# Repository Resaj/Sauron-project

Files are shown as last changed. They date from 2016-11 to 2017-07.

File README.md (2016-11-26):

# Sauron project
This video scanner module is based on David Chatting's project [Arduino Eye Shield](http://www.davidchatting.com/arduinoeyeshield/).

Our finally purpose is adapting this scanner for reading the enviroment with competition robots like line-following or minisumo robots, but applying another microcontroller with higher proccesing speed.

<p align="center">
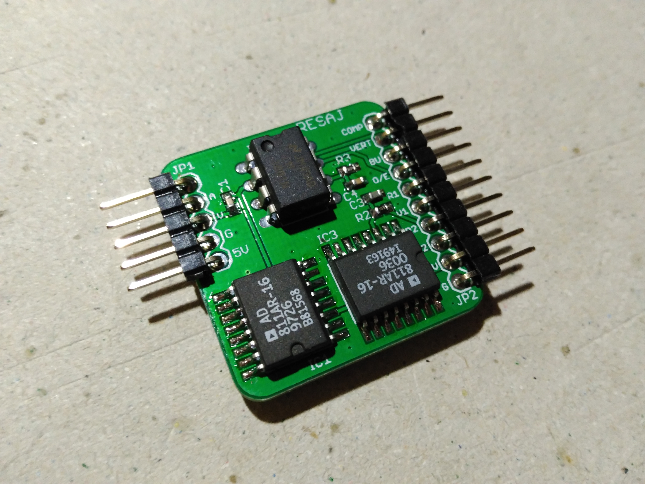
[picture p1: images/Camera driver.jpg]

</p>

## Author
[Rubén Espino San José](https://github.com/Resaj)

## License
<p align="center">

</p>

Todos estos productos están liberados mediante [Creative Commons Attribution-ShareAlike 4.0 International License](http://creativecommons.org/licenses/by-sa/4.0/).  
_All these products are released under [Creative Commons Attribution-ShareAlike 4.0 International License](http://creativecommons.org/licenses/by-sa/4.0/)._

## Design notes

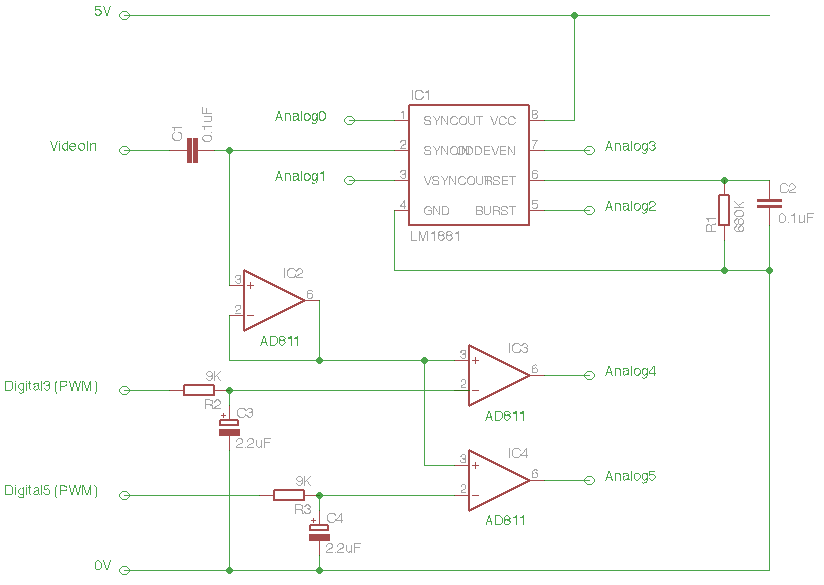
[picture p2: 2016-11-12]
images/ArduinoEyeShield-circuit.png

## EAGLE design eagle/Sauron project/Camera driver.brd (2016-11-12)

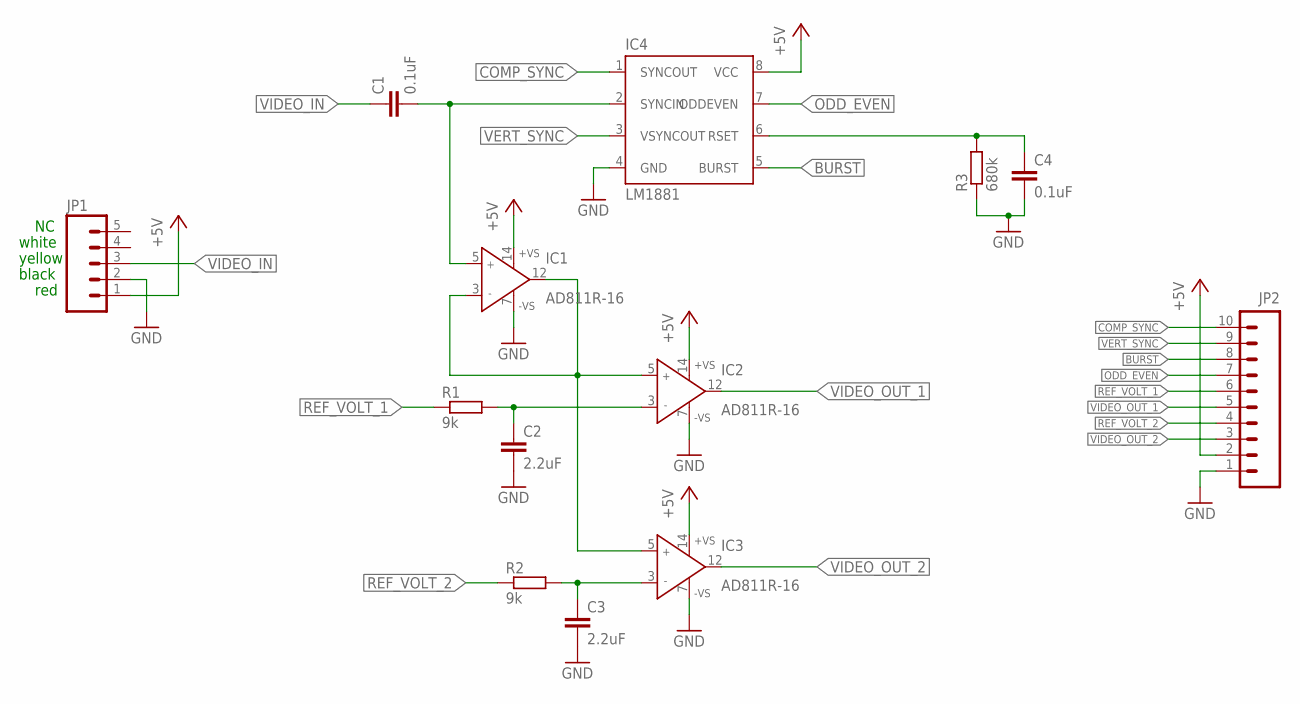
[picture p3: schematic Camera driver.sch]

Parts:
C1, C4: 0.1uF; C0603
C2, C3: 2.2uF; C0603
IC1, IC2, IC3: AD811R-16; SOIC16R
IC4: LM1881; DIL08
JP1: M05PTH; 1X05
JP2: M10SILK_FEMALE_PTH; 1X10
R1, R2: 9k; R0603
R3: 680k; R0603

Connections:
+5V: IC1.14 (+VS), IC2.14 (+VS), IC3.14 (+VS), IC4.8 (VCC), JP1.1, JP2.2
BURST: IC4.5 (BURST), JP2.8
COMP_SYNC: IC4.1 (SYNCOUT), JP2.10
GND: C2.2, C3.2, C4.2, IC1.7 (-VS), IC2.7 (-VS), IC3.7 (-VS), IC4.4 (GND), JP1.2, JP2.1, R3.1
unnamed: IC1.3 (IN-), IC1.12 (OUT), IC2.5 (IN+), IC3.5 (IN+)
unnamed: C4.1, IC4.6 (RSET), R3.2
unnamed: C3.1, IC3.3 (IN-), R2.2
unnamed: C1.2, IC1.5 (IN+), IC4.2 (SYNCIN)
unnamed: C2.1, IC2.3 (IN-), R1.2
ODD_EVEN: IC4.7 (ODDEVEN), JP2.7
REF_VOLT_1: JP2.6, R1.1
REF_VOLT_2: JP2.4, R2.1
VERT_SYNC: IC4.3 (VSYNCOUT), JP2.9
VIDEO_IN: C1.1, JP1.3
VIDEO_OUT_1: IC2.12 (OUT), JP2.5
VIDEO_OUT_2: IC3.12 (OUT), JP2.3

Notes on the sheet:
white
yellow
black
red

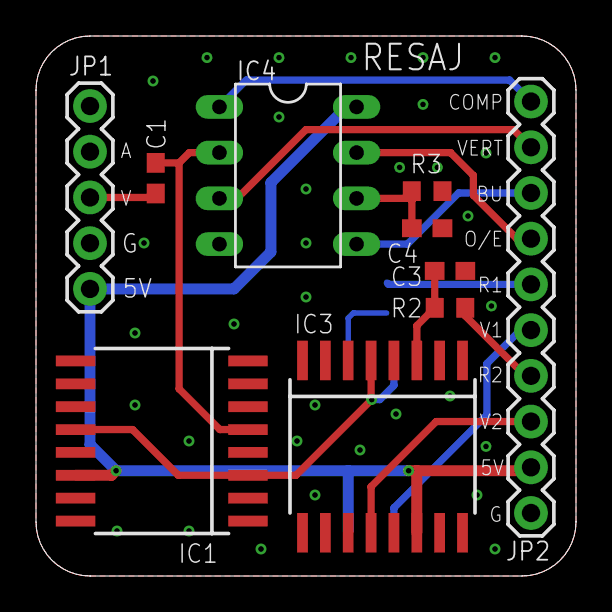
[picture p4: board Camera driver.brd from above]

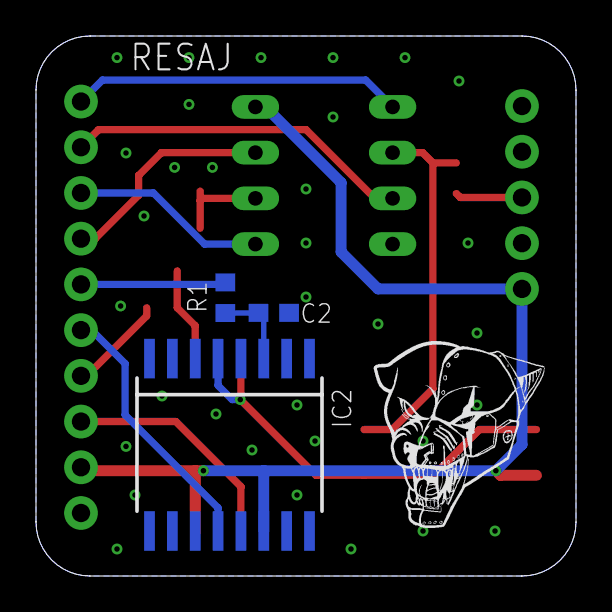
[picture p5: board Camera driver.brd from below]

Board: 2 copper layers, 30.0 x 30.0 mm, 14 parts (4 on the bottom side), 16 nets.

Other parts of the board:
U$1: LOGO_PUMA_10X10

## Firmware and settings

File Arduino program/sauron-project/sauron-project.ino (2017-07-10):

//David Chatting - david@davidchatting.com
//29th March 2010
//---
// Modified by Rubén Espino

#include "LedControlMS.h"

#define DISPLAY_LED
//#define PROCESSING_INTERFACE

#define compSyncPin 14  //A0  LM1881N:  PIN 1
#define vertSyncPin 15  //A1            PIN 3
#define burstPin    16  //A2            PIN 5
#define oddEvenPin  17  //A3            PIN 7
#define videoPin1   18  //A4
#define videoPin2   19  //A5

#define refVoltagePin1 3
#define refVoltagePin2 5

#define linesInPicture 625  //PAL

LedControl lc=LedControl(12,11,10,1); //DIN, SCK, CS, número de matrices

int numSamplesX = 8;
int numSamplesY = 8;

#define STARTING       0
#define GETTING_X_DIM  1
#define GETTING_Y_DIM  2
#define INITIALIZED    3
int init_state = STARTING;

int lineCount=1;
#define MAX_SAMPLES_X  25
#define MAX_SAMPLES_Y  25
int picture[MAX_SAMPLES_X][MAX_SAMPLES_Y];

int everyNthLine = floor((linesInPicture/2)/numSamplesY);

void setup() {
  int init = 0;
  char inByte = 0;
  
  pinMode(compSyncPin,INPUT);
  pinMode(vertSyncPin,INPUT);
  pinMode(burstPin,INPUT);
  pinMode(oddEvenPin,INPUT);
  
  pinMode(videoPin1,INPUT);
  pinMode(videoPin2,INPUT);
  
  pinMode(refVoltagePin1,OUTPUT);
  pinMode(refVoltagePin2,OUTPUT);
  setRefVoltage(refVoltagePin1, 1.7f);
  setRefVoltage(refVoltagePin2, 3.3f);

#ifdef PROCESSING_INTERFACE
  Serial.begin(115200);

  numSamplesX = 0;
  numSamplesY = 0;

  while(init_state != INITIALIZED)
  {
    if(Serial.available() > 0)
    {
      inByte = Serial.read();
      
      switch(init_state)
      {
        case STARTING:
          if(inByte == 'X')
            init_state = GETTING_X_DIM;
          break;
        case GETTING_X_DIM:
          if(inByte >= '0' && inByte <= '9')
            numSamplesX = numSamplesX*10 + inByte - 48;
          else if(inByte == 'Y' && numSamplesX != 0 && numSamplesX <= MAX_SAMPLES_X)
            init_state = GETTING_Y_DIM;
          else
          {
            if(numSamplesX > MAX_SAMPLES_X)
              Serial.print('E');
            numSamplesX = 0;
            init_state = STARTING;
          }
          break;
        case GETTING_Y_DIM:
          if(inByte >= '0' && inByte <= '9')
            numSamplesY = numSamplesY*10 + inByte - 48;
          else if(inByte == 'S' && numSamplesY != 0 && numSamplesY <= MAX_SAMPLES_Y)
          {
            Serial.print("KKK");
            init_state = INITIALIZED;
          }
          else
          {
            if(numSamplesY > MAX_SAMPLES_Y)
              Serial.print('E');
            numSamplesX = 0;
            numSamplesY = 0;
            init_state = STARTING;
          }
      }
    }
  }
#endif

#ifdef DISPLAY_LED
lc.shutdown(0,false);
lc.setIntensity(0,8);
lc.clearDisplay(0);
#endif
}

void loop(){
  int y=0;
  
  if(~(1<<3)&PINC){ // if(!digitalRead(oddEvenPin)){
    while(~(1<<3)&PINC); // while(!digitalRead(oddEvenPin));
    while(~(1<<1)&PINC); // while(!digitalRead(vertSyncPin));
    
    while((1<<3)&PINC){ // while(digitalRead(oddEvenPin)){
      if((lineCount%everyNthLine)==0){
        //off the shelf analogRead: takes approx 0.1 mS = 100 uS on Decimilla, but 1 line takes 64 uS - boo!
        //hacked version (16) 16 samples in 1000 17ms => 1 sample and write in 17 uS'ish => can do 3 samples of video signal
        //a digital read does 1000 samples and writes in 4mS => 4us per sample => good! => 16 samples
        //line=0;
        
        for(int x=0;x<numSamplesX;++x){
          char state = 0;
          state = PINC;
          picture[x][y] = (1<<4)&state + (1<<5)&state; // picture[x][y] = digitalRead(videoPin1) + digitalRead(videoPin2);
        }

        ++y;
      }
      ++lineCount;
      
      while((1<<2)&PINC); // while(digitalRead(burstPin));
    }
    //this now happens on the odd frame...

    setLEDs();
    lineCount=1;
  }
}

void setLEDs(){
#ifdef DISPLAY_LED
  for(int j=0;j<numSamplesY;++j){
    for(int i=0;i<numSamplesX;++i){
      if(picture[i][j] > 0)
        lc.setLed(0,i,j,true);
      else
        lc.setLed(0,i,j,false);
    }
  }
#endif

#ifdef PROCESSING_INTERFACE
  Serial.println('S');

  for(int y=0;y<numSamplesY;++y){
    for(int x=0;x<numSamplesX;++x){
      Serial.print(picture[x][y]);
    }
    Serial.println();
  }
  Serial.println();
#endif
}

void setRefVoltage(int refVoltagePin, float v){
  if(v>=0 && v<=5.0){
    analogWrite(refVoltagePin,(255*v)/5);
  }
}

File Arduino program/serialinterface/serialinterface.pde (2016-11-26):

import processing.serial.*;

Serial myPort;  // Create object from Serial class
int val;      // Data received from the serial port
int t = 0;
int x = 0, y = 0;
int i = 0, j = 0;
int fps = 0;
int frames = 0;
int inByte = 0;

final int windowSizeX = 300;
final int windowSizeY = 350;

int numSamplesX = 3;
int numSamplesY = 3;
int[][] picture = new int[numSamplesX][numSamplesY];
int pictureX_min = 10, pictureX_max = windowSizeX-10;
int pictureY_min = 10, pictureY_max = windowSizeY-60;

String m[] = {"X", nf(numSamplesX), "Y", nf(numSamplesY), "S"};
String msg = join(m, "");

boolean initialized = false;

void setup() 
{
  size(300, 350);
  // I know that the first port in the serial list on my mac
  // is always my  FTDI adaptor, so I open Serial.list()[0].
  // On Windows machines, this generally opens COM1.
  // Open whatever port is the one you're using.
  String portName = Serial.list()[0];
  myPort = new Serial(this, portName, 115200);
}

void draw()
{
  if(!initialized)
  {
    background(255,0,0);
    textSize(20);
    fill(0);
    text("Initializing...", 50, 50);
    
    if(myPort.available() > 0)
    {
      inByte = myPort.read();
      if(inByte == 'E')
        text("Dimension error!!", 50, 100);
      else if(inByte == 'K')
        initialized = true;
        t = 0;
    }
    else if(millis() - t > 200)
    {
      myPort.write(msg);
      t = millis();
    }
  }
  else
  {
    if(myPort.available() > 0)
    {
      inByte = myPort.read();

      if(inByte == 'S')
      {
        x = 0;
        y = 0;
        frames++;
      }
      else if(inByte == '0' || inByte == '1' || inByte == '2')
      {
        picture[x][y] = inByte - 48;
        x++;
        if(x == numSamplesX)
        {
          x = 0;
          y++;
        }
      }
    
      if(millis() - t > 1000)
      {
        fps = frames;
        frames = 0;
        t = millis();
      }
    }
    
    background(0,255,0);
    fill(0);
    text("fps:", 50, windowSizeY-25);
    text(fps, 100, windowSizeY-25);

    for(j=0; j<numSamplesY; j++)
    {
      for(i=0; i<numSamplesX; i++)
      {
        switch(picture[i][j])
        {
          case 0:
            fill(255);
            break;
          case 1:
            fill(127);
            break;
          case 2:
            fill(0);
        }
        rect(/*x_min*/pictureX_min + i*floor((pictureX_max-pictureX_min)/numSamplesX),
             /*y_min*/pictureY_min + j*floor((pictureY_max-pictureY_min)/numSamplesY),
             /*x_dist*/ceil((pictureX_max-pictureX_min)/numSamplesX),
             /*y_dist*/ceil((pictureY_max-pictureY_min)/numSamplesY));
      }
    }
  }
}

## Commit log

2016-11-26 Arduino program actualized and processing interface added
2017-02-16 Led matrix added for testing

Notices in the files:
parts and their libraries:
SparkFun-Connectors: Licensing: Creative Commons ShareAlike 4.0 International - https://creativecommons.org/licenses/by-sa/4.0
